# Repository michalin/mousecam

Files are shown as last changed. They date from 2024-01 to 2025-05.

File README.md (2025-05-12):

# ESP32 Code for the "Mouse To Camera Hack"
Displays frames captured by an optical mouse sensor on a simple web user interface. Works with all optical mice with ADNS 2610 sensor. 
## Parts Needed
- Waveshare ESP32 S3 Mini module
- Raspberry Pi wide angle camera lens f=1.7mm or similar
- Lens adapter, see [example](cad/)
- Microsoft Code with PlatformIO extension
## Usage
- Remove controller chip or extract Pin 3 and 4 of the sensor.
- Connect pin 3 of sensor to pin 2 of the ESP32 module (SDIO)
- Connect pin 4 of sensor to pin 1 of the ESP32 module (Clock)
- Enter your SSID and passkey into [main.cpp](code/src/main.cpp)  
`const char *ssid = "your ssid";`  
`const char *password = "your password";`
- Compile and flash the sketch
- Open the local file [code/data/index.htm](code/data/index.htm) in your browser.
## Important Note
**The ESP32 API has changed from versions 2.X (based on ESP-IDF 4.4) to version 3.0 (based on ESP-IDF 5.1) of the Arduino ESP32 core. Only compiles against version 2.X.**

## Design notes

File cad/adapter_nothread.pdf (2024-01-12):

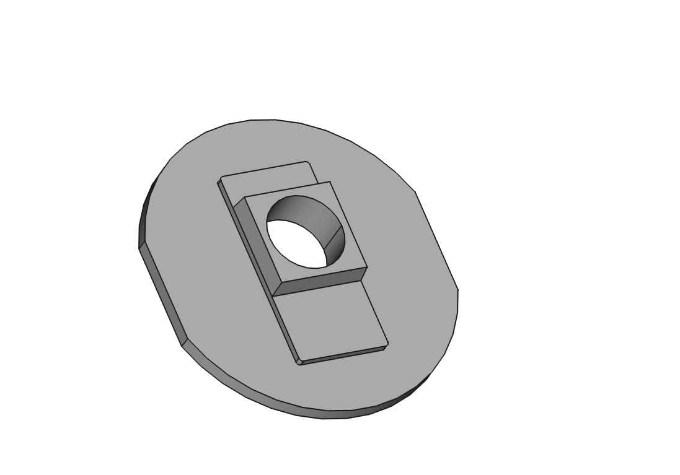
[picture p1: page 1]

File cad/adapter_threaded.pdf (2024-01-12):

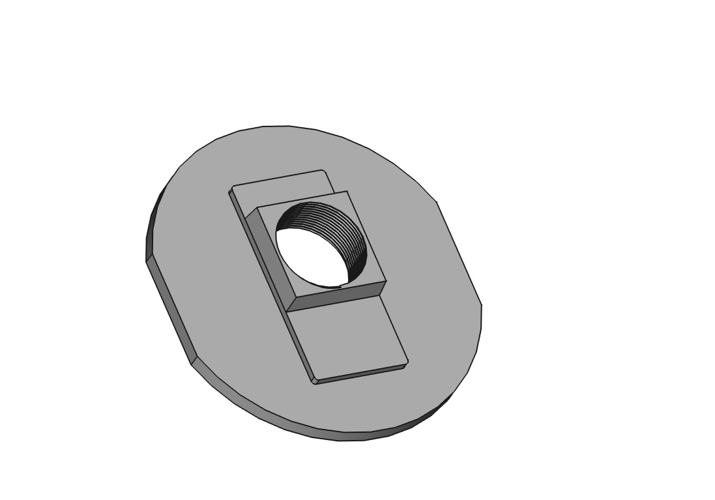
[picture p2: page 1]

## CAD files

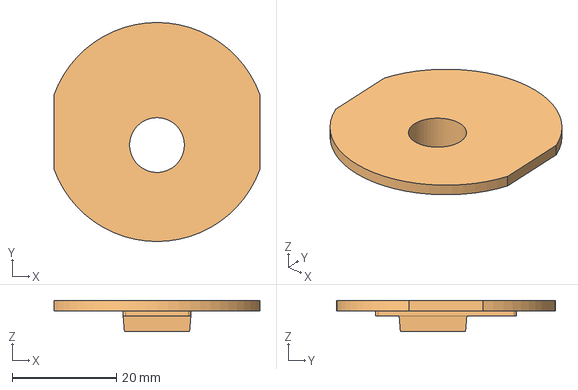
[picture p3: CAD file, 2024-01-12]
cad/adapter.FCStd
39.5 x 42.0 x 6.00 mm
threaded
nothread

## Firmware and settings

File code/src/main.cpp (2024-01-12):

/*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
 You should have received a copy of the GNU General Public License
 along with this program.  If not, see <https://www.gnu.org/licenses></https:>.
*/

#include "Arduino.h"
#include "esp32-hal.h"
#include <ArduinoJson.h>
#include <driver/timer.h>

#define SCK_PIN GPIO_NUM_1  /* Clock (pin 4 of ADNS 2610) */
#define SDIO_PIN GPIO_NUM_2 /* Bidirectional serial data (pin 3 of ADNS 2610)*/
#define REG_CONFIG 0        /* Configuration register */
#define REG_CONFIG_WAKEUP 1
#define REG_CONFIG_RESET 128
#define REG_SQUAL 4      /* Surface Quality */
#define REG_DATA 8       /* Pixel data register */
#define REG_DATA_VALID 6 /* Set if pixel data is valid */
#define CMD_SCAN 1
#define CMD_ACK 3
#define LED 21

#define INTENS 32 /*Brightness of LED*/
#define RED 0, INTENS, 0         
#define YELLOW INTENS, INTENS, 0 
#define GREEN INTENS, 0, 0       
#define BLUE 0, 0, INTENS        

//#define TEST /*send a simple test pattern*/

const char *ssid = "******";
const char *password = "******";
hw_timer_t *scn_timer = NULL;
bool connected = false;
int speed = 1000;

void web_init(const char *ssid, const char *password);
void web_write(const char *data);
void web_cleanup();

void reg_write(uint8_t reg, uint8_t val)
{
    uint16_t to_write = reg;
    to_write <<= 8;
    to_write |= 0x8000 + val;
    // Serial.printf("reg: %d, val: %d, to_write: %d\n", reg, val, to_write);
    pinMode(SDIO_PIN, OUTPUT);
    gpio_set_level(SDIO_PIN, HIGH);
    gpio_set_level(SCK_PIN, HIGH);
    // Register number and value to sensor
    for (int b = 0; b < 16; b++)
    {
        gpio_set_level(SCK_PIN, LOW);
        gpio_set_level(SDIO_PIN, (to_write << b) & 0x8000);
        gpio_set_level(SCK_PIN, HIGH);
    }
    gpio_set_level(SDIO_PIN, LOW);
    pinMode(SDIO_PIN, INPUT);
}

uint8_t reg_read(uint8_t reg)
{
    pinMode(SDIO_PIN, OUTPUT);
    gpio_set_level(SDIO_PIN, HIGH);
    gpio_set_level(SCK_PIN, HIGH);
    // Register number to sensor
    for (int b = 0; b < 8; b++)
    {
        gpio_set_level(SCK_PIN, LOW);
        gpio_set_level(SDIO_PIN, (reg << b) & 0x80);
        gpio_set_level(SCK_PIN, HIGH);
        gpio_set_level(SCK_PIN, HIGH); // Extend a bit
    }
    gpio_set_level(SDIO_PIN, LOW);
    pinMode(SDIO_PIN, INPUT);
    delayMicroseconds(80); // Give sensor some time to prepare response
    uint8_t val = 0;
    // Clock in value
    for (int b = 7; b >= 0; b--)
    {
        gpio_set_level(SCK_PIN, LOW);
        gpio_set_level(SCK_PIN, LOW);
        gpio_set_level(SCK_PIN, HIGH);
        val |= gpio_get_level(SDIO_PIN) << b;
        gpio_set_level(SCK_PIN, HIGH);
    }
    return val;
}

void send_image()
{
    // Serial.println("-->send_image()");
    neopixelWrite(LED, BLUE);
    DynamicJsonDocument jdoc(8192);
    jdoc["squal"] = reg_read(REG_SQUAL);
    JsonArray jarray = jdoc.createNestedArray("data");
    reg_write(REG_DATA, 1); //Capture frame 
    delay(10);
    for (int i = 0; i < 324; i++) //Dump frame buffer pixel by pixel
    {
        uint8_t pixval = 0;
        uint32_t time = millis();
#ifdef TEST
        pixval = i;
        delayMicroseconds(100);
#else        
        pixval = reg_read(REG_DATA);
#endif
        jarray.add(pixval & 0x3F);
        delayMicroseconds(speed);
    }
    char buf[1400];
    memset(buf, 0, 1400);
    neopixelWrite(LED, GREEN);
    serializeJson(jdoc, buf);
    serializeJson(jdoc, Serial);
    web_write(buf);
    neopixelWrite(LED, YELLOW);
}

TaskHandle_t Task1;
void handleWebMessage(const char *data, size_t len)
{
    // Serial.println(data);
    StaticJsonDocument<200> jdoc;
    deserializeJson(jdoc, data);
    switch ((int)jdoc["cmd"])
    {
    case CMD_ACK:
        send_image();
        break;
    }
    speed = 1500 - 100 * (int)jdoc["speed"];
    Serial.println(speed);
}

void on_connect()
{
    neopixelWrite(LED, GREEN);
    reg_write(REG_CONFIG, REG_CONFIG_RESET);
    delay(100);
    reg_write(REG_CONFIG, REG_CONFIG_WAKEUP);
    send_image();
    connected = true;
}
void on_disconnect()
{
    neopixelWrite(LED, RED);
    connected = false;
}

void setup()
{
    pinMode(SCK_PIN, OUTPUT);
    digitalWrite(LED, HIGH);
    neopixelWrite(LED, RED);
    Serial.begin(115200);
    delay(1000);
    web_init(ssid, password);
}

void loop()
{
    web_cleanup();
}

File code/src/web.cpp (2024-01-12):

/*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
 You should have received a copy of the GNU General Public License
 along with this program.  If not, see <https://www.gnu.org/licenses></https:>.
*/

//#define AP_MODE /* Provides AP with IP 192.168.4.1 */
#define LOCAL_WEB /* Web UI located on PC */

#include <WiFi.h>
#include <AsyncTCP.h>
#include <ESPAsyncWebServer.h>
//#include <ESPAsyncWebSrv.h>
#ifndef LOCAL_WEB
  #include <SPIFFS.h>
#endif
#include <mdns.h>

// mdns hostname
const char *hostname = "mousecam.local";

void handleWebMessage(const char *data, size_t len);
void on_connect() __attribute__((weak));
void on_disconnect(); // __attribute__((weak));

// Create AsyncWebServer object on port 80
AsyncWebServer server(80);
AsyncWebSocket ws("/ws");

void onEvent(AsyncWebSocket *server, AsyncWebSocketClient *client, AwsEventType type,
             void *arg, uint8_t *data, size_t len)
{
  switch (type)
  {
  case WS_EVT_CONNECT:
    // Serial.printf("WebSocket client #%u connected from %s\n", client->id(), client->remoteIP().toString().c_str());
    on_connect();
    break;
  case WS_EVT_DISCONNECT:
    // Serial.printf("WebSocket client #%u disconnected\n", client->id());
    on_disconnect();
    break;
  case WS_EVT_DATA:
    // handleWebSocketMessage(arg, data, len);
    {
      AwsFrameInfo *info = (AwsFrameInfo *)arg;
      if (info->final && info->index == 0 && info->len == len && info->opcode == WS_TEXT)
      {
        handleWebMessage((const char *)data, len);
      }
    }
  }
}

String processor(const String &var)
{
  // Serial.print("processor");
  // Serial.println(var);
  if (var == "STATE")
  {
  }
  return "Hello";
}

void web_init(const char *ssid, const char *password)
{
  // Connect to Wi-Fi
#ifdef AP_MODE
  WiFi.softAP(ssid, password);;
  IPAddress IP = WiFi.softAPIP();
  Serial.printf("AP IP address: %s\n", IP.toString());
#else  
  WiFi.begin(ssid, password);
  Serial.print("Connecting to WiFi");
  while (WiFi.status() != WL_CONNECTED)
  {
    Serial.print(".");
    delay(500);
  }
  Serial.println();
  Serial.println("WiFi Connected");
#endif  

  // Assign DNS name
  mdns_init();
  mdns_hostname_set(hostname);

  ws.onEvent(onEvent);
  server.addHandler(&ws);

// Initialize SPIFFS
#ifndef LOCAL_WEB
  Serial.printf("Open http://%s in browser\r\n", hostname);
  if (!SPIFFS.begin(true))
  {
    Serial.println("An Error has occurred while mounting SPIFFS");
    return;
  }
  server.serveStatic("/", SPIFFS, "/");
#endif

// Magic to allow access to event server from anywhere
  DefaultHeaders::Instance().addHeader(F("Access-Control-Allow-Origin"), F("*"));
// DefaultHeaders::Instance().addHeader(F("Access-Control-Allow-Credentials"), F("true"));
  // Start server
  server.begin();
}

void web_write(const char *data)
{
  while (!ws.availableForWriteAll())
  {
    Serial.println("Waiting for websocket");
    vTaskDelay(10);
  }
  ws.textAll(data);
}

void web_cleanup()
{
  ws.cleanupClients();
}

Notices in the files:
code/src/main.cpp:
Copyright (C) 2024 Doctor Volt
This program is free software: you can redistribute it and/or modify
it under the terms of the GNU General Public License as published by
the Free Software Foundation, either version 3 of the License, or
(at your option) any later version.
